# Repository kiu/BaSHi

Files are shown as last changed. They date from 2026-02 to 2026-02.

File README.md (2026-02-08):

# BaSHi
BaSHi - Bidirectional adapter for Sniffing Home appliances (isolated)

[Hajo](https://github.com/hn/) gave a [talk](https://media.ccc.de/v/39c3-hacking-washing-machines) on hacking home appliances at the [39C3](https://events.ccc.de/congress/2025/infos/startpage.html). That talk inspired me to build a simple, isolated, bidirectional D-Bus adapter to make tinkering with these devices easier.

# Warning
> [!WARNING]
> Household appliances work with high voltages and currents. Even if parts of the appliances operate at low voltages, they may or may not be isolated from earth and in case of a fault, can expose dangerous voltages. There is a good chance of death or serious injury. They might generate heat and steam, shake, vibrate, have rotating parts and get wet. Take appropriate safety measures.

| :zap: I'm neither responsible nor liable if you kill your cat, your spouse, yourself, or set your house on fire. You have been warned. BaSHi is intended to be used by experts, e.g., electricians.  |
|------------------------------------------|

# Usage
BaSHi can operate in two modes.

In <ins>non-isolated</ins> mode, the ESP32 is powered by the home appliance. Both jumpers must be shorted. This mode is intended for standalone operation. Do not connect the ESP32 USB port while BaSHi is connected to a home appliance.

In <ins>isolated</ins> mode, the ESP32 is electrically isolated from the home appliance. Bothe jumpers must be left open. This mode is intended for development. The ESP32 must be powered via its USB port.

Hint: Once you have identified the wires carrying D-BUS, use quick splice connectors (commonly used in automotive applications) to tap in BaSHi.

# Variants
BaSHi comes in two variants. Choose the variant based on the ESP32 board you want to use.

Note: While layout and pin usage differ between the two PCB variants, they share the same stencil, enclosure, and components (with the exception of J4 and J5).

## BaSHi-SM-1
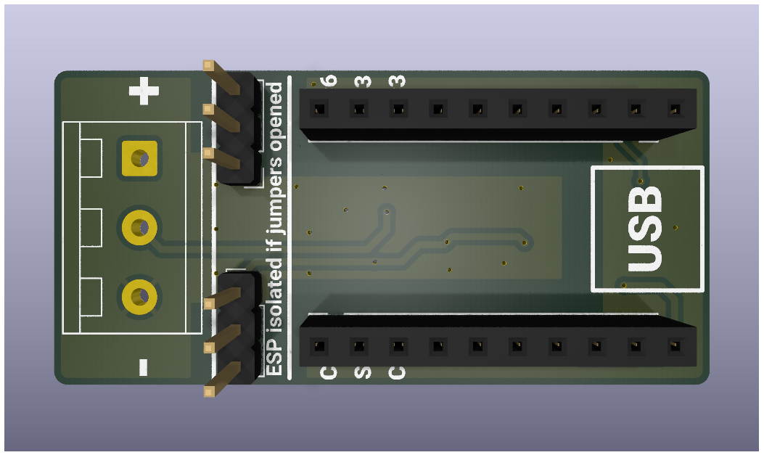
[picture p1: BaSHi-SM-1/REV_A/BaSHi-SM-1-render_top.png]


Install: BaSHi-SM-1 is compatible with ESP32 boards of varying pin counts. The board must be bottom-aligned with the USB port at the lowest pin; the markings at the top provide additional guidance.

- [KiCad](BaSHi-SM-1/REV_A/kicad/): KiCad [schematic](BaSHi-SM-1/REV_A/BaSHi-SM-1-schematic.png), board and gerbers
- Compatibility: [ESP32 C3 Super Mini](https://www.espboards.dev/esp32/esp32-c3-super-mini/), [ESP32 C3 Super Mini Plus](https://www.espboards.dev/esp32/esp32-c3-super-mini-plus/), [ESP32 C6 Super Mini](https://www.espboards.dev/esp32/esp32-c6-super-mini/) and [ESP32 S3 Super Mini](https://www.espboards.dev/esp32/esp32-s3-super-mini/)

## BaSHi-ZERO-1
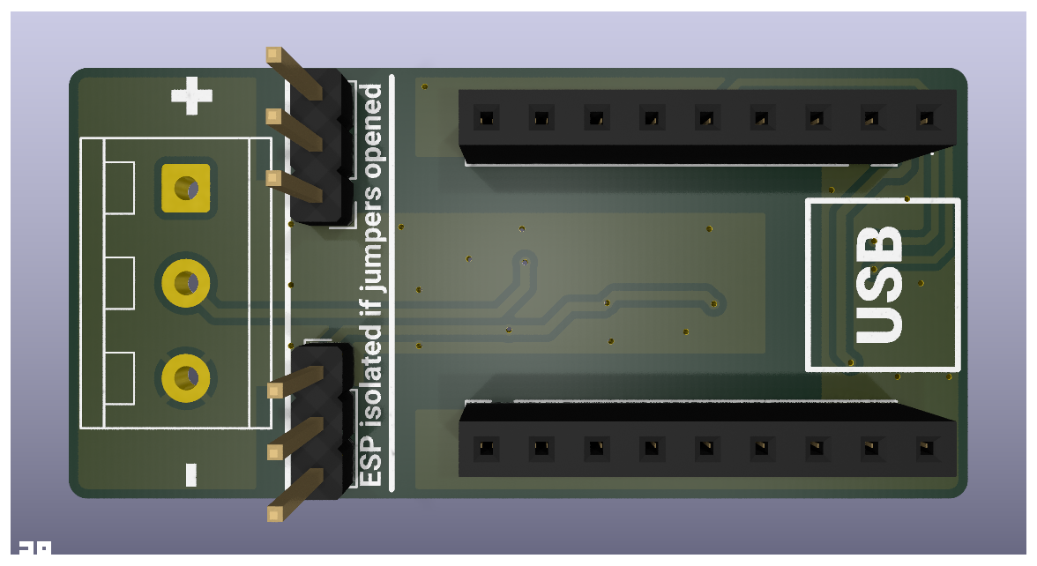
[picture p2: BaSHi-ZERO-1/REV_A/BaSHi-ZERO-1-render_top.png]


Install: For BaSHi-ZERO-1, all compatible ESP32 boards share the same pin count. Ensure the board is bottom-aligned with the USB port at the lowest pin.

- [KiCad](BaSHi-ZERO-1/REV_A/kicad/): KiCad [schematic](BaSHi-ZERO-1/REV_A/BaSHi-ZERO-1-schematic.png), board and gerbers
- Compatibility: [ESP32 C3 Zero](https://www.espboards.dev/esp32/esp32-c3-zero/), [ESP32 C6 Zero Mini](https://www.espboards.dev/esp32/esp32-c6-zero-mini/), [ESP32 S3 Zero](https://www.espboards.dev/esp32/esp32-s3-zero/)

## Common Files
The following files apply to both BaSHi variants.

- [Sketch](common/bsh-dbus-logger/): Adapted Arduino sketch (Bus2USB Bridge)
- [Mech](common/mech/): Simple OpenSCAD enclosure
- [BOM](common/BaSHi-boms.ods): Bills of materials ([PDF](common/BaSHi-boms.pdf))
- [Datasheets](common/datasheets/): Datasheets of main components

# Links
- https://github.com/hn/bsh-home-appliances/
- https://media.ccc.de/v/39c3-hacking-washing-machines
- https://de.wikipedia.org/wiki/RAST-Steckverbinder

# License
This project is licensed under the Creative Commons Attribution-NonCommercial 3.0 Unported (CC BY-NC 3.0) license.

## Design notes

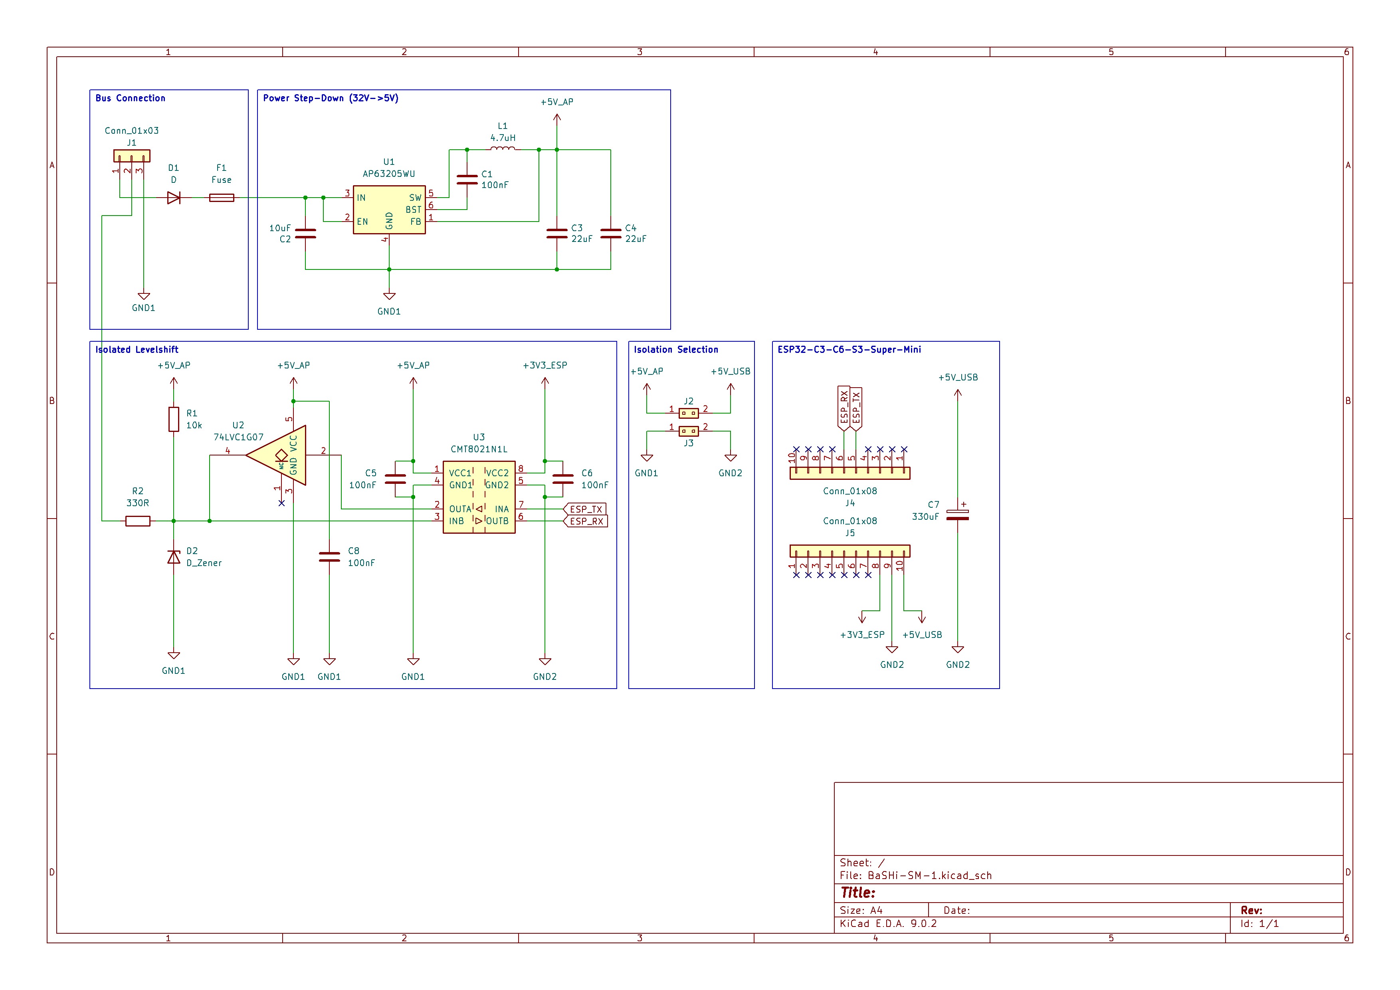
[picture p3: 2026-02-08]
BaSHi-SM-1/REV_A/BaSHi-SM-1-schematic.png

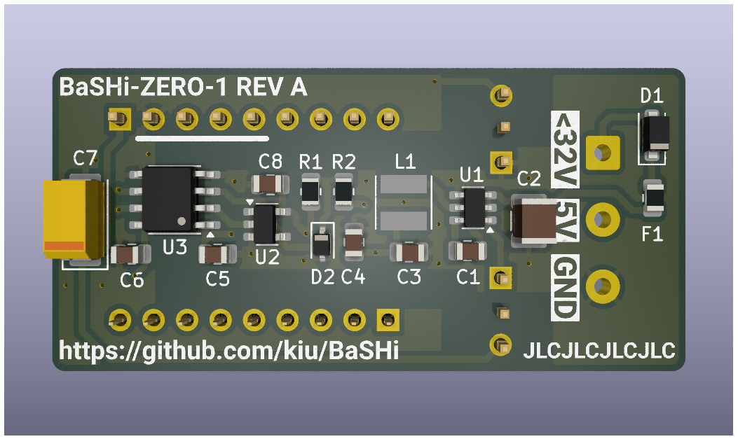
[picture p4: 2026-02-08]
BaSHi-ZERO-1/REV_A/BaSHi-ZERO-1-render_bottom.png

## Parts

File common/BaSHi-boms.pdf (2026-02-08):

BaSHi-common

Page 1

Designator | Description | Req | Price | Price (sum) | Provider | ID
MOQ 10
U1 | AP63205WU Step-Down | 1 | 0,2547 € | 0,2547 € | | C2071056
U2 | 74LVC1G07 | 1 | 0,0266 € | 0,0266 € | | C48391414
U3 | Isolator CMT8021N1L 10Mbps | 1 | 0,1799 € | 0,1799 € | | C32713171
D1 | Diode 123F | 1 | 0,0038 € | 0,0038 € | | C3008061
D2 | Zener 5.1V SOD-323 | 1 | 0,0135 € | 0,0135 € | | C110757
F1 | Fuse 0805 33V 500mA | 1 | 0,0477 € | 0,0477 € | | C25838740
L1 | 4.7uH 2.3A | 1 | 0,0300 € | 0,0300 € | | C5159668
C1,C5,C6,C8 | 100nF 0805 | 4 | 0,0100 € | 0,0400 € | | C49678
J1 | 1x03 5.08 Terminal | 1 | 0,1596 € | 0,1596 € | | C72334
J2, J3 | 1x03 2.54 Header (Modify Manually) | 2 | 0,0137 € | 0,0274 € | | C2937625
J4, J5 | See other sheets | 0
C2 | 10uF 1210 100V | 1 | 0,2800 € | 0,2800 € | | C576517
C3,C4 | 22uF 0805 10V | 2 | 0,0200 € | 0,0400 € | | C6119895
C7 | 330uF Tantalum C | 1 | 0,3529 € | 0,3529 € | | C11377
R1 | 10k 0805 | 1 | 0,0011 € | 0,0011 € | | C2930231
R2 | 330R 0805 | 1 | 0,0046 € | 0,0046 € | | C2918550
- | Jumper Alternative (2x) | 0 | 0,5164 € | 0,0000 € | | C587231
- | Jumper 5.08 Black | 1 | 0,1910 € | 0,1910 € | | CAB5ZS
- | Jumper 5.08 Red | 1 | 0,2310 € | 0,2310 € | | CAB5ZR
| | | | SUM
| | | | 1,88 €
| | | | 18,84 €

www.lcsc.com
www.lcsc.com
www.lcsc.com
www.lcsc.com
www.lcsc.com
www.lcsc.com
www.lcsc.com
www.lcsc.com
www.lcsc.com
www.lcsc.com

www.lcsc.com
www.lcsc.com
www.lcsc.com
www.lcsc.com
www.lcsc.com
www.lcsc.com
www.tme.eu
www.tme.eu

BaSHi-SM-1

Page 2

Designator | Description | Req | Price | Price (sum) | Provider | ID
MOQ 10
J4,J5 | 1x10 2.54 Socket | 2 | 0,1355 € | 0,2710 € | | C41376159
| | | | SUM
| | | | 0,27 €
| | | | 2,71 € | www.lcsc.com

BaSHi-ZERO-1

Page 3

Designator | Description | Req | Price | Price (sum) | Provider | ID
MOQ 10
J4,J5 | 1x09 2.54 Socket | 2 | 0,1271 € | 0,2542 € | | C27985234
| | | | SUM
| | | | 0,25 €
| | | | 2,54 € | www.lcsc.com

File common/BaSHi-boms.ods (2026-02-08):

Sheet: BaSHi-common
Designator | Description | Req | Price | Price (sum) | Provider | ID
 |  |  | MOQ | 10
U1 | AP63205WU Step-Down | 1 | 0,2547 € | 0,2547 € | www.lcsc.com | C2071056
U2 | 74LVC1G07 | 1 | 0,0266 € | 0,0266 € | www.lcsc.com | C48391414
U3 | Isolator CMT8021N1L 10Mbps | 1 | 0,1799 € | 0,1799 € | www.lcsc.com | C32713171
D1 | Diode 123F | 1 | 0,0038 € | 0,0038 € | www.lcsc.com | C3008061
D2 | Zener 5.1V SOD-323 | 1 | 0,0135 € | 0,0135 € | www.lcsc.com | C110757
F1 | Fuse 0805 33V 500mA | 1 | 0,0477 € | 0,0477 € | www.lcsc.com | C25838740
L1 | 4.7uH 2.3A | 1 | 0,0300 € | 0,0300 € | www.lcsc.com | C5159668
C1,C5,C6,C8 | 100nF 0805 | 4 | 0,0100 € | 0,0400 € | www.lcsc.com | C49678
J1 | 1x03 5.08 Terminal | 1 | 0,1596 € | 0,1596 € | www.lcsc.com | C72334
J2, J3 | 1x03 2.54 Header (Modify Manually) | 2 | 0,0137 € | 0,0274 € | www.lcsc.com | C2937625
J4, J5 | See other sheets | 0
C2 | 10uF 1210 100V | 1 | 0,2800 € | 0,2800 € | www.lcsc.com | C576517
C3,C4 | 22uF 0805 10V | 2 | 0,0200 € | 0,0400 € | www.lcsc.com | C6119895
C7 | 330uF Tantalum C | 1 | 0,3529 € | 0,3529 € | www.lcsc.com | C11377
R1 | 10k 0805 | 1 | 0,0011 € | 0,0011 € | www.lcsc.com | C2930231
R2 | 330R 0805 | 1 | 0,0046 € | 0,0046 € | www.lcsc.com | C2918550
- | Jumper Alternative (2x) | 0 | 0,5164 € | 0,0000 € | www.lcsc.com | C587231
- | Jumper 5.08 Black | 1 | 0,1910 € | 0,1910 € | www.tme.eu | CAB5ZS
- | Jumper 5.08 Red | 1 | 0,2310 € | 0,2310 € | www.tme.eu | CAB5ZR
 |  |  |  | SUM
 |  |  |  | 1,88 €
 |  |  |  | 18,84 €

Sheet: BaSHi-SM-1
Designator | Description | Req | Price | Price (sum) | Provider | ID
 |  |  | MOQ | 10
J4,J5 | 1x10 2.54 Socket | 2 | 0,1355 € | 0,2710 € | www.lcsc.com | C41376159
 |  |  |  | SUM
 |  |  |  | 0,27 €
 |  |  |  | 2,71 €

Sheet: BaSHi-ZERO-1
Designator | Description | Req | Price | Price (sum) | Provider | ID
 |  |  | MOQ | 10
J4,J5 | 1x09 2.54 Socket | 2 | 0,1271 € | 0,2542 € | www.lcsc.com | C27985234
 |  |  |  | SUM
 |  |  |  | 0,25 €
 |  |  |  | 2,54 €

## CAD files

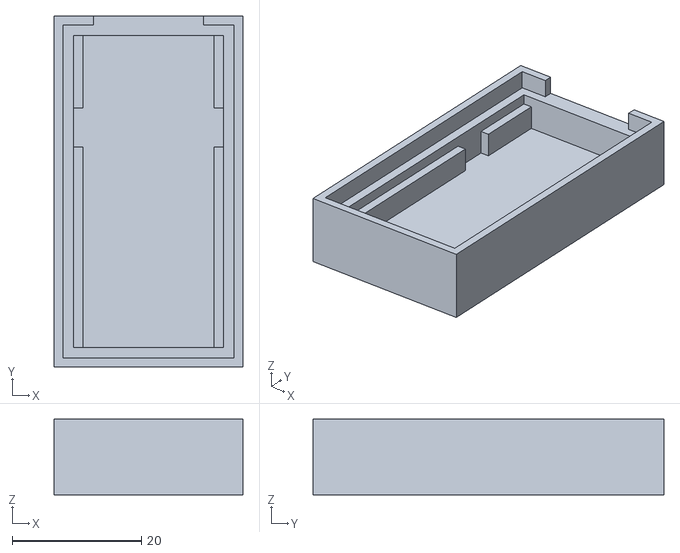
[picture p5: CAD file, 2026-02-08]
common/mech/BaSHi-case-bottom.stl
29.2 x 54.2 x 11.7

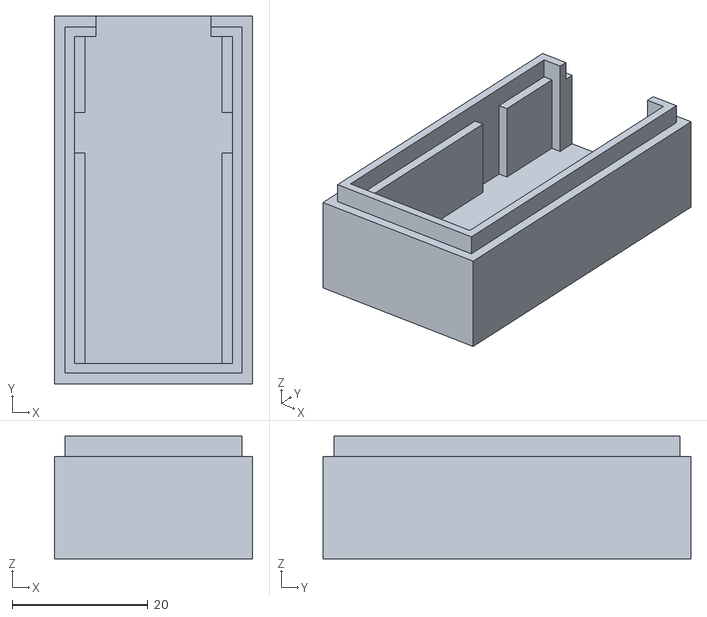
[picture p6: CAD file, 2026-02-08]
common/mech/BaSHi-case-top.stl
29.2 x 54.2 x 18.1

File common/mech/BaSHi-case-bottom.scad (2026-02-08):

include <./BaSHi-case-common.scad>

// -------------------------------------------------------

case_bottom(48);

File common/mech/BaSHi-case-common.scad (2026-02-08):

$fn = $preview?6:360;

thick = 3;
tolerance = 0.1;

pcb_width = 23;

pcb_top = 15;
pcb_thick = 1.6;
pcb_bottom = 4;

cut_terminal_width = 17;

cut_top_pcb_offset = 31;
cut_top_pcb_height = 6;

pcb_border = 1.5;

box_inner_x = pcb_width + 2 * tolerance;
box_outer_x = box_inner_x + 2 * thick;

lip_width = thick / 2 - tolerance;
lip_height = 3;

// -------------------------------------------------------

b_box_inner_x_pcb = pcb_width - 2 * pcb_border + 2 * tolerance;

b_box_inner_z = pcb_bottom + pcb_thick + tolerance;
b_box_outer_z = b_box_inner_z + thick;

// --------------------------------------------------------

t_box_inner_z = pcb_top + tolerance - lip_height;
t_box_outer_z = t_box_inner_z + thick;

// --------------------------------------------------------

module case_top(pcb_height) {    
    box_inner_y = pcb_height + 2 * tolerance;
    box_outer_y = box_inner_y + 2 * thick;
    
    difference() {
        
        union() {
            // Initial box
            cube ([box_outer_x, box_outer_y, t_box_outer_z]);

            // Lip
            translate([thick - lip_width, thick - lip_width, t_box_outer_z])
                cube ([lip_width, box_outer_y - thick - lip_width, lip_height]);
            translate([box_outer_x - thick, thick - lip_width, t_box_outer_z])
                cube ([lip_width, box_outer_y - thick - lip_width, lip_height]);
            translate([thick - lip_width, thick - lip_width, t_box_outer_z])
                cube ([box_outer_x - 2 * thick  + 2 * lip_width, lip_width, lip_height]);
            translate([thick - lip_width, box_outer_y - thick, t_box_outer_z])
                cube ([box_outer_x - 2 * thick + 2 * lip_width, lip_width, lip_height]);
        }

        // Remove inner for pcb
        translate([box_outer_x/2 - b_box_inner_x_pcb/2, box_outer_y/2 - box_inner_y/2, thick])
            cube ([b_box_inner_x_pcb, box_inner_y, t_box_inner_z]);

        // Cutout inner for pcb
        translate([box_outer_x/2 - box_inner_x/2, thick + cut_top_pcb_offset, thick])
            cube ([box_inner_x, cut_top_pcb_height, t_box_inner_z]);

        // Remove Terminal        
        translate([box_outer_x/2 - cut_terminal_width/2, box_outer_y - thick, thick])
            cube ([cut_terminal_width, box_outer_y, t_box_inner_z + lip_height]);
    }
}

module case_bottom(pcb_height) {
    box_inner_y = pcb_height + 2 * tolerance;
    box_outer_y = box_inner_y + 2 * thick;
    
    difference() {
        
        union() {
            // Initial box
            cube ([box_outer_x, box_outer_y, b_box_outer_z]);
            
            // Lip
            translate([0, 0, b_box_outer_z])
                cube ([lip_width, box_outer_y, lip_height]);
            translate([box_outer_x - lip_width, 0, b_box_outer_z])
                cube ([lip_width, box_outer_y, lip_height]);
            translate([0, 0, b_box_outer_z])
                cube ([box_outer_x, lip_width, lip_height]);
            translate([0, box_outer_y - lip_width, b_box_outer_z])
                cube ([box_outer_x, lip_width, lip_height]);       
        }
        
        // Remove for pcb
        translate([box_outer_x/2 - box_inner_x/2, box_outer_y/2 - box_inner_y/2, b_box_outer_z - pcb_thick - tolerance])
            cube ([box_inner_x, box_inner_y, pcb_thick + tolerance]);

        // Cutout inner for pcb
        translate([box_outer_x/2 - box_inner_x/2, thick + cut_top_pcb_offset, thick])
            cube ([box_inner_x, cut_top_pcb_height, t_box_inner_z]);

        // Remove inner
        translate([box_outer_x/2 - b_box_inner_x_pcb/2, box_outer_y/2 - box_inner_y/2, thick])
            cube ([b_box_inner_x_pcb, box_inner_y, b_box_inner_z]);

        // Remove lip
        translate([box_outer_x/2 - cut_terminal_width/2, box_outer_y - thick, thick + b_box_inner_z])
            cube ([cut_terminal_width, box_outer_y, lip_height]);
        
        translate([box_outer_x/2 - b_box_inner_x_pcb/2, box_outer_y/2 - box_inner_y/2, thick])
            cube ([b_box_inner_x_pcb, box_inner_y, b_box_inner_z]);

    }
   
}

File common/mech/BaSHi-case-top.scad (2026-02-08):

include <./BaSHi-case-common.scad>

// -------------------------------------------------------

case_top(48);

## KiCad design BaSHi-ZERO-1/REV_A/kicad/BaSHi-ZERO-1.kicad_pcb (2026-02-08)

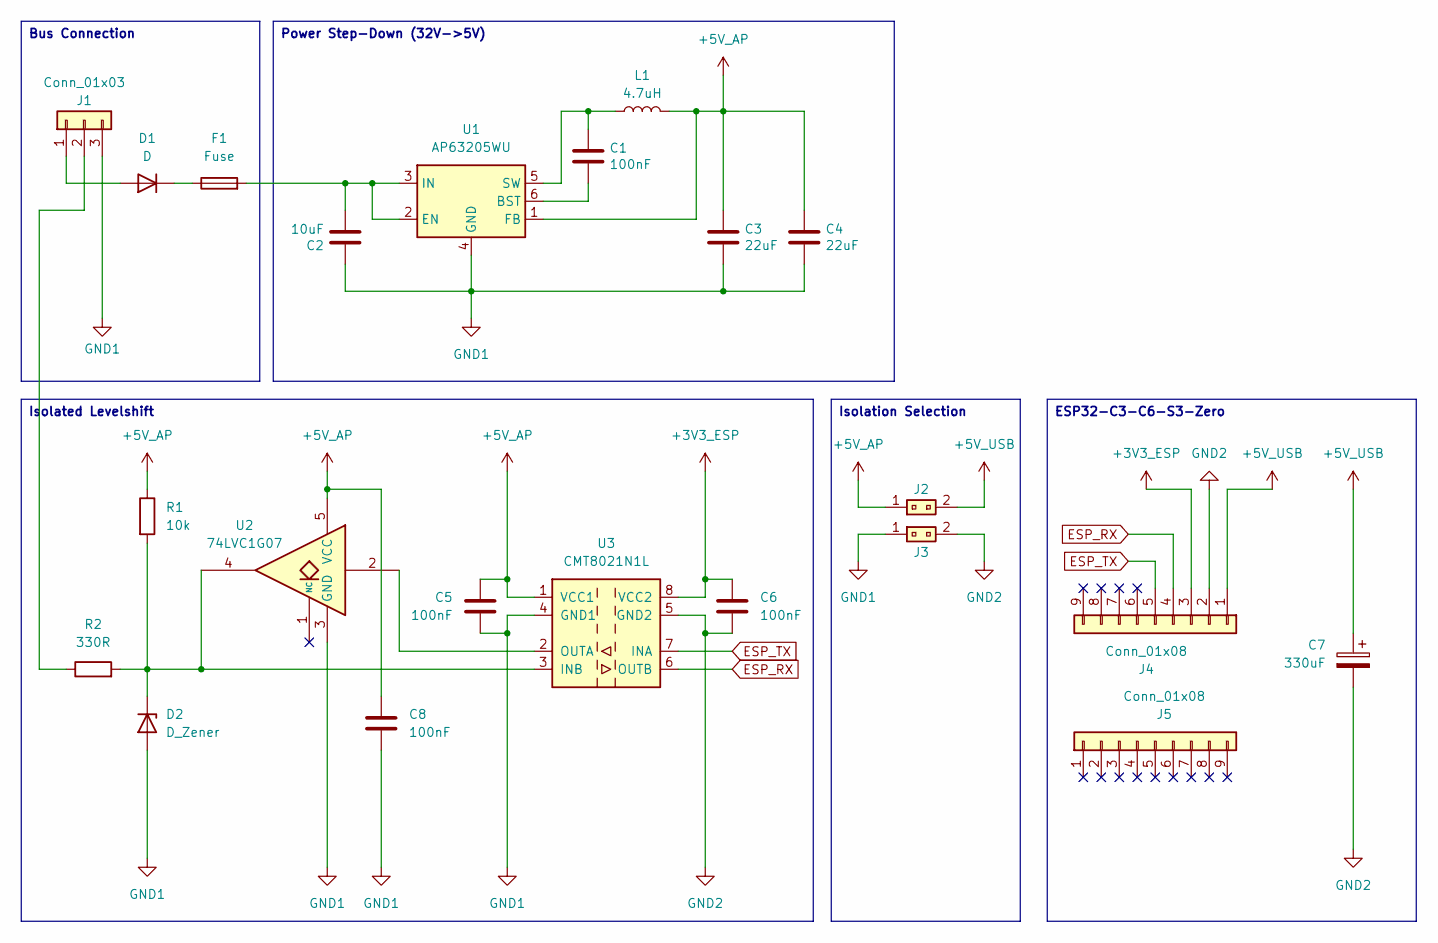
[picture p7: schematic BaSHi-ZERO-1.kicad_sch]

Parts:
C1, C5, C6, C8: 100nF; C_0805_2012Metric; LCSC C49678
C2: 10uF; C_1210_3225Metric; LCSC C576517
C3, C4: 22uF; C_0805_2012Metric; LCSC C6119895
C7: 330uF; CP_EIA-6032-28_Kemet-C; LCSC C11377
D1: D; D_SOD-123F; LCSC C3008061
D2: D_Zener; D_SOD-323; LCSC C110757
F1: Fuse; Fuse_0805_2012Metric; LCSC C25838740
J1: Conn_01x03; TerminalBlock_1x03_P5.08mm_Horizontal_WJ500V-5.08-03P-14-00A; LCSC C72334
J2, J3: 1x02_Jumper; PinHeader_1x03_1PMissing_P2.54mm_Vertical; LCSC C2937625
J4, J5: Conn_01x08; PinSocket_1x09_P2.54mm_Vertical; LCSC C27985234
L1: 4.7uH; L_SFE4018A-4R7M-F-HF_4x4x1.8mm; LCSC C5159668
R1: 10k; R_0805_2012Metric; LCSC C2930231
R2: 330R; R_0805_2012Metric; LCSC C2918550
U1: AP63205WU; TSOT-23-6; LCSC C2071056
U2: 74LVC1G07; SOT-23-5; LCSC C48391414
U3: CMT8021N1L; SOIC-8_3.9x4.9mm_P1.27mm; LCSC C32713171

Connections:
+3V3_ESP: C6.1, J4.3, U3.8 (VCC2)
+5V_AP: C3.1, C4.1, C5.2, C8.2, J2.1, L1.2, R1.1, U1.1 (FB), U2.5 (VCC), U3.1 (VCC1)
+5V_USB: C7.1, J2.2, J4.1
ESP_RX: J4.4, U3.6 (OUTB)
ESP_TX: J4.5, U3.7 (INA)
GND1: C2.1, C3.2, C4.2, C5.1, C8.1, D2.2 (A), J1.3, J3.1, U1.4 (GND), U2.3 (GND), U3.4 (GND1)
GND2: C6.2, C7.2, J3.2, J4.2, U3.5 (GND2)
unnamed: D1.2 (A), J1.1
unnamed: D1.1 (K), F1.1
unnamed: D2.1 (K), R1.2, R2.2, U2.4, U3.3 (INB)
unnamed: J1.2, R2.1
unnamed: C1.2, U1.6 (BST)
unnamed: C2.2, F1.2, U1.2 (EN), U1.3 (IN)
unnamed: C1.1, L1.1, U1.5 (SW)
unnamed: U2.2, U3.2 (OUTA)

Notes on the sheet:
Isolated Levelshift
Power Step-Down (32V->5V)
Bus Connection
Isolation Selection
ESP32-C3-C6-S3-Zero

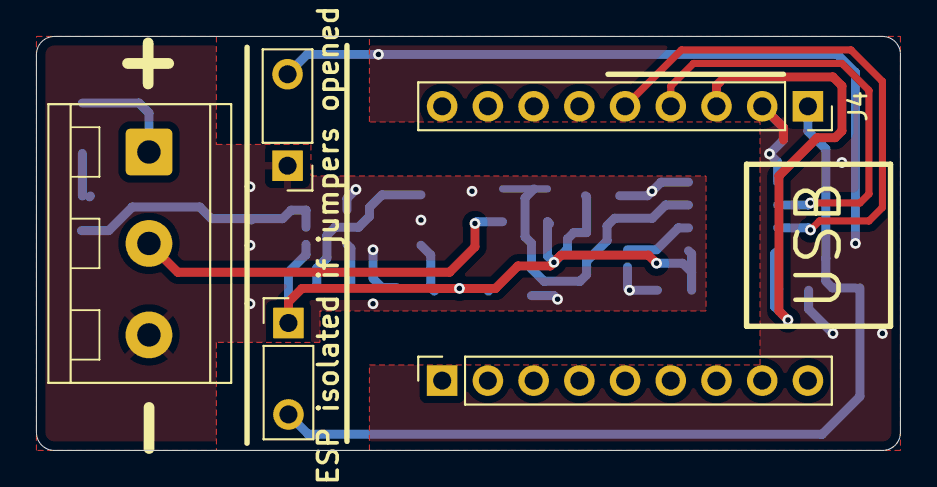
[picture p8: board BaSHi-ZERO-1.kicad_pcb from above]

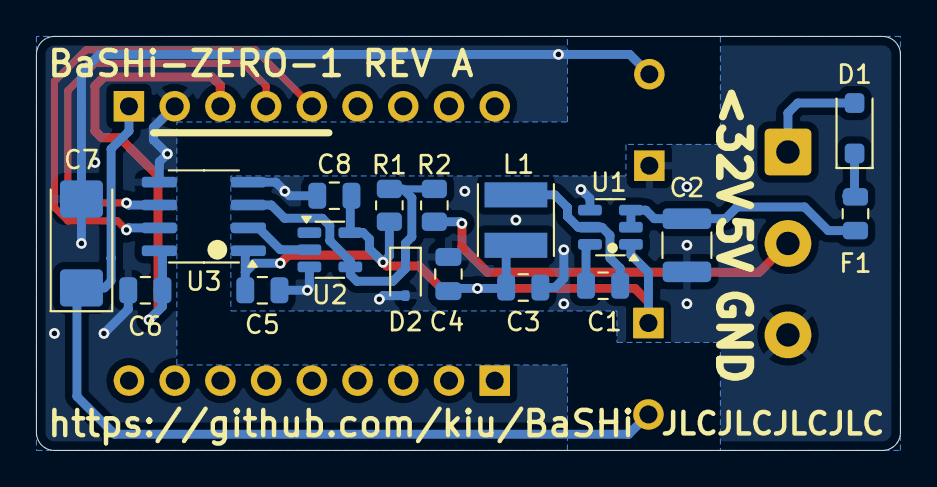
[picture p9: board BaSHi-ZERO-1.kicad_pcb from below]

Board: 2 copper layers, 48.0 x 23.0 mm, 22 parts (17 on the bottom side), 15 nets.

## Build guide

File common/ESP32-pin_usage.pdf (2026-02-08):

ESP32 SM

Seite 1

C6 | S3 | H2 | C3 | | C3 | H2 | S3 | C6
TX | TX | 24 TX | 5 MTDI / FL | 1 | 5V | 5V | 5V | 5V
RX | RX | 23 RX | 6 MTCK / FL | 2 | GND | GND GND | GND
0 | 1 0 FL | 7 MTDO / FL | 3 | 3V3 | 3V3 | 3V3 | 3V3
1 | 2 1 FL | 8 BOOT HIGH / LED | 4 | 4 MTMS / FL | 14 | 13 FL | 20
| 2 3 BOOT OUT | 2 MTMS / FL | 9 BOOT HIGH | 5 | 3 | 13 | 12 FL | 19 FL
3 | 4 3 MTDO / FL | 10 | 6 | 2 BOOT HIGH | 12 | 11 FL | 18 FL
4 MTMS / FL / BOOT | | 5 4 MTCK / FL | 20 RX | 7 | 1 | 11 | 10 FL | 15 JTAG / LED
5 MTDI / FL / BOOT | | 6 5 MTDI / FL | 21 TX | 8 | 0 | 10 | 9 FL | 14
6 MTCK / FL | | 7 8 BOOT / LED | | 9 | | 9 BOOT HIGH | 8 | 9 BOOT HIGH / RGB
7 MTDO / FL | | | | 10 | | | | 8 BOOT HIGH

ESP32 ZERO

Seite 2

C6 | S3 | C3 | | C3 | S3 | C6
5V | 5V | 5V | 1 | TX | TX | TX
GND | GND | GND | 2 | RX | RX | RX
3V3 | 3V3 | 3V3 | 3 | 19 | 13 | 14
0 | 1 | 0 | 4 | 18 | 12 | 15
1 | 2 | 1 | 5 | 10 | 11 | 18
2 | 3 | 2 6 | 9 | 10 | 19
3 | 4 | 3 | 7 | 8 LED | 9 | 20
4 | 5 | 4 8 | 7 | 8 | 21
5 | 6 | 5 9 | 6 | 7 | 22

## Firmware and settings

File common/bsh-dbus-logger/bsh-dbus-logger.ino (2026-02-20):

/*
   bsh-dbus-logger.ino

   B/S/H/ D-Bus data logger

   (C) 2024 Hajo Noerenberg

   http://www.noerenberg.de/
   https://github.com/hn/bsh-home-appliances

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
   You should have received a copy of the GNU General Public License along
   with this program. If not, see <http://www.gnu.org/licenses/gpl-3.0.txt>.
*/

/*
   Slightly adapted for use with https://github.com/kiu/BaSHi
*/

// Arduino IDE
// Library manager: Install "CRC" by Rob Tillaart https://github.com/RobTillaart/CRC
// Library manager: Install "FastLED" by Daniel Garcia https://github.com/FastLED/FastLED
// Boards manager: Install "esp32" https://github.com/espressif/arduino-esp32
// Config: Set "USB CDC on Boot" to "Enabled"

// Compatibility BaSHi-SM-1
// ESP32-C3-SUPER-MINI (Black)
// ESP32-C3-SUPER-MINI-PLUS (Red) [Unverified / LED needs to be configured below]
// ESP32-C6-SUPER-MINI (Black)
// ESP32-S3-SUPER-MINI (Black)

// Compatibility BaSHi-ZERO-1
// ESP32-C3-ZERO (Blue)
// ESP32-C6-ZERO (Blue)
// ESP32-S3-ZERO (Blue)

// RGB LED
// blue   = RX byte received
// green  = RX CRC ok
// red    = RX CRC fail
// purple = TX bye

// ---------------------------------------------------------------------------

#ifdef ARDUINO_ESP32C3_DEV
#define RX_PIN 10
#define TX_PIN 9
#define LED_TYPE 0  // Blue LED
#define LED_PIN 8
#define LED_ON LOW
#define LED_OFF HIGH
//#define LED_TYPE 1  // RGB LED SUPER_MINI_PLUS ONLY
//#define LED_PIN 8 // SUPER_MINI_PLUS ONLY
#endif

#ifdef ARDUINO_ESP32C6_DEV
#define RX_PIN 3
#define TX_PIN 2
//#define LED_TYPE 0 // Blue LED
//#define LED_PIN 15
//#define LED_ON HIGH
//#define LED_OFF LOW
#define LED_TYPE 1  // RGB LED
#define LED_PIN 8
#define LED_COLOR_ORDER GRB
#endif

#ifdef ARDUINO_ESP32S3_DEV
#define RX_PIN 4
#define TX_PIN 3
#define LED_TYPE 1  // RGB LED
#define LED_PIN 48
#define LED_COLOR_ORDER GRB
#endif

#ifdef ARDUINO_WAVESHARE_ESP32_C3_ZERO
#define RX_PIN 0
#define TX_PIN 1
#define LED_TYPE 1  // RGB LED
#define LED_PIN 10
#define LED_COLOR_ORDER GRB
#endif

#ifdef ARDUINO_WAVESHARE_ESP32_C6_ZERO
#define RX_PIN 0
#define TX_PIN 1
#define LED_TYPE 1  // RGB LED
#define LED_PIN 8
#define LED_COLOR_ORDER RGB
#endif

#ifdef ARDUINO_WAVESHARE_ESP32_S3_ZERO
#define RX_PIN 1
#define TX_PIN 2
#define LED_TYPE 1  // RGB LED
#define LED_PIN 21
#define LED_COLOR_ORDER GRB
#endif

// ---------------------------------------------------------------------------

#include "CRC16.h"
#include "CRC.h"

#if LED_TYPE == 1
#include <FastLED.h>
CRGB leds[1];
#endif

#define FRAMEBUFLEN 64
#define USERBUFLEN 32

#define serial_usb Serial
#define serial_dbus Serial0

// ---------------------------------------------------------------------------

CRC16 crc(CRC16_XMODEM_POLYNOME,
          CRC16_XMODEM_INITIAL,
          CRC16_XMODEM_XOR_OUT,
          CRC16_XMODEM_REV_IN,
          CRC16_XMODEM_REV_OUT);

byte framebuf[FRAMEBUFLEN];
unsigned int framepos = 0;
unsigned int framelen = 0;
unsigned long readlast = 0;
char userbuf[USERBUFLEN];
unsigned int userlen = 0;

// ---------------------------------------------------------------------------

void led_init() {
#ifdef LED_PIN
  pinMode(LED_PIN, OUTPUT);
#if LED_TYPE == 1
  FastLED.addLeds<WS2812, LED_PIN, LED_COLOR_ORDER>(leds, 1);
#endif
  led_set(0, 0);
#endif
}

void led_set(uint8_t color, uint8_t ms) {
#ifdef LED_PIN

#if LED_TYPE == 0
  if (color == 0) {
    digitalWrite(LED_PIN, LED_OFF);
  } else {  // Blue
    digitalWrite(LED_PIN, LED_ON);
  }
#endif

#if LED_TYPE == 1
  if (color == 0 || color > 4) {
    leds[0] = CRGB::Black;
  }
  if (color == 1) {
    leds[0] = CRGB::Green;
  }
  if (color == 2) {
    leds[0] = CRGB::Red;
  }
  if (color == 3) {
    leds[0] = CRGB::Blue;
  }
  if (color == 4) {
    leds[0] = CRGB::Purple;
  }
  FastLED.show();
#endif

  delay(ms);

  if (color > 0) {
    led_set(0,0);
  }

#endif
}

// ---------------------------------------------------------------------------

void setup() {
  serial_dbus.begin(9600, SERIAL_8N1, RX_PIN, TX_PIN);

  delay(500);

  led_init();
  serial_usb.begin(115200);
  serial_usb.println("\n\nB/S/H/ D-Bus logger started.");
}

void loop() {
  while (serial_dbus.available()) {
    unsigned long readnow = millis();
    byte rawbyte = serial_dbus.read();

    if ((readnow - readlast) > 40) {
      if ((framelen > 0) && (framepos == framelen)) {
        serial_usb.printf("(ack=none)\n");
      } else if (framepos > 0) {
        serial_usb.printf("(read=timout)\n");
      }
      framepos = framelen = 0;
      crc.restart();
    } else if ((framelen > 0) && (framepos == framelen)) {
      framepos = framelen = 0;
      crc.restart();
      // Strictly speaking, this should not be necessary here
      // if the timing is precise, so it is a kind of workaround:
      if (rawbyte == ((framebuf[1] & 0xf0) | 0x0a)) {
        serial_usb.printf("%02x (ack=ok)\n", rawbyte);
        continue;
      } else {
        serial_usb.printf("(ack=err, re-evaluate byte)\n");
      }
    }

    readlast = readnow;
    crc.add(rawbyte);
    serial_usb.printf("%02x", rawbyte);
    led_set(3, 15);
    if (framepos < FRAMEBUFLEN) {
      framebuf[framepos++] = rawbyte;
    }

    if (framepos == 1) {
      framelen = 2 + 2 + (unsigned int)rawbyte;
      serial_usb.printf(" | ");
    } else if (framepos == 2) {
      serial_usb.printf(".");
    } else if (framepos == 3) {
      serial_usb.printf("-");
    } else if (framepos == 4) {
      serial_usb.printf(" | ");
    } else if (framepos == (framelen - 2)) {
      for (unsigned int p = framelen; p < 10; p++) {
        serial_usb.printf("   ");
      }
      serial_usb.printf(" | ");
    } else if (framepos == framelen) {
      if (crc.calc()) {
        serial_usb.printf(" (crc=err, len=%d)\n", framelen);
        led_set(2, 80);
        framepos = framelen = 0;
        crc.restart();
      } else {
        serial_usb.printf(" (crc=ok) | ");
        led_set(1, 80);
        // We only process a small sample set of data here:
        switch (framebuf[1] << 16 | framebuf[2] << 8 | framebuf[3]) {
          case 0x141004:
            serial_usb.printf("(Temperature=%d) ", framebuf[4]);
            break;
          case 0x141005:
            serial_usb.printf("(Washing program=%d) ", framebuf[6]);
            break;
          case 0x141006:
            serial_usb.printf("(Spin speed=%d) ", framebuf[4]);
            break;
          case 0x2a1600:
            serial_usb.printf("(Remaining time=%d) ", framebuf[4]);
            break;
        }
      }
    } else {
      serial_usb.printf(" ");
    }
  }

  // Dirty way to write to the D-Bus: No silence / collision / anything detection, just fire and forget
  // Input via terminal: DS.CC-CC MM MM (no length prefix, no crc)

  while (serial_usb.available()) {
    byte c = serial_usb.read();
    if (((c >= '0' && c <= '9') || (c >= 'A' && c <= 'F') || (c >= 'a' && c <= 'f')) && userlen < USERBUFLEN) {
      userbuf[userlen++] = c;
    }
    if (c != '\r' && c != '\n') continue;
    if (userlen == 0) break;
    if (userlen < 6 || userlen % 2) {
      serial_usb.println("Error: Invalid input length");
      userlen = 0;
      continue;
    }
    CRC16 outcrc(CRC16_XMODEM_POLYNOME, CRC16_XMODEM_INITIAL, CRC16_XMODEM_XOR_OUT, CRC16_XMODEM_REV_IN, CRC16_XMODEM_REV_OUT);
    byte outbyte = userlen / 2 - 1;    
    outcrc.add(outbyte);
    led_set(4, 80);
    serial_dbus.write(outbyte);
    for (unsigned int i = 0; i < userlen; i += 2) {
      outbyte = (userbuf[i] % 32 + 9) % 25 * 16 + (userbuf[i + 1] % 32 + 9) % 25;
      outcrc.add(outbyte);
      serial_dbus.write(outbyte);
    }
    uint16_t outcc = outcrc.calc();
    serial_dbus.write(outcc >> 8);
    serial_dbus.write(outcc);
    userlen = 0;
  }
}

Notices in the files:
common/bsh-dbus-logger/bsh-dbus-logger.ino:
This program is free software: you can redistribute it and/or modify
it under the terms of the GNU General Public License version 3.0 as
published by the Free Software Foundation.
